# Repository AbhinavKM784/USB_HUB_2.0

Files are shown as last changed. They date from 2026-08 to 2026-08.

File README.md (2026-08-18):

# USB 4 port 2.0 Hub

A custom-designed 4-port USB 2.0 hub built around the GL850G USB Hub Controller.

## Overview

This USB hub features:

- 1 × USB C upstream port
- 2 × USB Type-A downstream ports
- 2 × USB Type-C downstream ports
- USB 2.0 High-Speed support (up to 480 Mbps)
- Plug-and-play operation

## Specifications

- Hub Controller - GL850G 
- USB Standard - USB 2.0
- Maximum Speed - 480 Mbps
- Upstream Ports - 1 
- USB-A Ports - 2 
- USB-C Ports - 2 

## Bill of Materials (BOM)

|  # | Component | Value / Part | Qty | Price (INR) | Price (USD) |
| -: | --- | --- | --: | ---: | ---: |
|  1 | PCB | Fabricated by LionCircuits | 1 | ₹1,012.00 | $10.626 |
|  2 | Capacitor | 10 µF | 2 | ₹21.60 | $0.2268 |
|  3 | Capacitor | 1 µF | 4 | ₹21.10 | $0.22155 |
|  4 | Capacitor | 22 pF | 2 | ₹20.00 | $0.210 |
|  5 | Capacitor | 100 nF | 5 | ₹19.00 | $0.1995 |
|  6 | USB IC | GL850G | 1 | ₹84.00 | $0.882 |
|  7 | USB-C Receptacle | USB 2.0, 16P | 3 | ₹71.00 | $0.7455 |
|  8 | USB-A Receptacle | Molex 67643 | 2 | ₹15.00 | $0.1575 |
|  9 | Resistor | 5.1 kΩ | 6 | ₹11.00 | $0.1155 |
| 10 | Resistor | 680 Ω | 1 | ₹13.00 | $0.1365 |
| 11 | Resistor | 10 kΩ | 1 | ₹11.00 | $0.1155 |
| 12 | Crystal | 12 MHz | 1 | ₹24.00 | $0.252 |
| 13 | Soldering Wire | 40/60, 0.8 mm | 1 | ₹53.00 | $0.5565 |
| 14 | Magnets | 3 mm Diameter × 3 mm Thick Neodymium | 8 | ₹76.00 | $0.798 |
| 15 | M2 Screws | M2 × 8 mm Phillips CSK SS 304 | 5 | ₹8.00 | $0.084 |
| 16 | M2 Brass Inserts | M2 × 6 mm Brass Threaded Inserts | 5 | ₹12.00 | $0.126 |
| | **Total** | | | **₹1,471.70** | **$15.45285** |

### Additional Hardware

* **8 × 3 mm × 3 mm neodymium magnets** — used for the enclosure's magnetic closure.
* **5 × M2 × 8 mm Phillips countersunk screws** — used for PCB mounting.
* **5 × M2 × 6 mm brass threaded inserts** — used as threaded mounting points for the PCB screws.

### Component Links

* [PCB — LionCircuits](https://www.lioncircuits.com/)
* [10 µF Capacitor — KTRON](https://www.ktron.in/product/10uf-25v-ceramic-capacitor-smd-0805/)
* [1 µF Capacitor — Robu](https://robu.in/product/gcm21br71e105ka56k-murata-electronics-25v-1uf-x7r-%c2%b110-0805-multilayer-ceramic-capacitor/)
* [22 pF Capacitor — KTRON](https://www.ktron.in/product/22pf-100v-multi-layered-ceramic-capacitor/)
* [100 nF Capacitor — KTRON](https://www.ktron.in/product/100nf-100v-ceramic-capacitor-0805/)
* [GL850G USB IC — Hubtronics](https://hubtronics.in/1884)
* [USB-C Receptacle — KTRON](https://www.ktron.in/product/mup-u20401-03-usb-type-c-16-pin-smd-connector/)
* [USB-A Receptacle — KTRON](https://www.ktron.in/product/usb-type-a-female-connector/)
* [5.1 kΩ Resistor — Robu](https://robu.in/product/erj6geyj512v-panasonic-125mw-thick-film-resistors/)
* [680 Ω Resistor — Robu](https://robu.in/product/rt0805fr-07680rl-yageo-125mw-thick-film-resistor/)
* [10 kΩ Resistor — Robu](https://robu.in/product/ac0805jr-0710kl-yageo-res-thick-film-0805-10k-ohm/)
* [12 MHz Crystal — KTRON](https://www.ktron.in/product/12-mhz-crystal-smd-hc49smd-xyc/)
* [Soldering Wire — Robu](https://robu.in/product/tin-wire-soldering-tubeus-0-8mm-40-60/)
* [3 mm × 3 mm Neodymium Magnets — OnlyScrews](https://onlyscrews.in/products/3mm-x-3mm-neodymium-disc-magnets-n35-dia-3mm-thickness-3mm)
* [M2 × 8 mm Phillips CSK Screws — OnlyScrews](https://onlyscrews.in/products/m2-x-8mm-phillips-csk-ss-304-screw-dia-2mm-length-8mm)
* [M2 × 6 mm Brass Threaded Inserts — OnlyScrews](https://onlyscrews.in/products/m2-x-6mm-brass-threaded-inserts)

### Shipping

| Supplier | Shipping (INR) | Shipping (USD) |
| --- | ---: | ---: |
| Hubtronics | ₹75.00 | $0.788 |
| Robu | ₹50.00 | $0.525 |
| Ktron | ₹77.00 | $0.809 |
| Onlyscrews | ₹59.00 | 0.7245 |

| **Shipping Total** |    **₹272.00** |     **2.8455** |

### Total Cost

| | INR | USD |
| --- | ---: | ---: |
| Components | ₹1,375.70 | $14.445 |
| Shipping | ₹202.00 | $2.121 |
| **Grand Total** | **₹1,742.70** | **$18.299** |

> **Note:** Prices are approximate and may change depending on supplier pricing and availability.

## Schematic



*Complete circuit schematic of the USB hub.*

## PCB Design



## 3D Model





## CAD Photos And Videos
Bottom Case

<video src="https://github.com/user-attachments/assets/de1a6d5d-6dac-484f-9280-b4399e31e206" controls width="800"></video>

Top Case

<video src="https://github.com/user-attachments/assets/451d31d9-74d8-4081-8db9-19cb0036360e" controls width="800"></video>


PCB 


Assembled Case

<video src="https://github.com/user-attachments/assets/695826ae-f8d0-41ed-982d-1c137125c4df" controls width="800"></video>

## Hardware Architecture

```text
          Host PC
              │
              ▼
       USB Upstream Port
              │
              ▼
          GL850G
      USB Hub Controller
        ┌────┴────┐
        │         │
   USB-A Ports  USB-C Ports
      (2x)         (2x)

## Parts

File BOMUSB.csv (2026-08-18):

PARTS
Sl no | Component | Value / Part | Qty | Link | Price (Inr) | Price(USD)
1 | PCB | Fabricated by lionscircuit | 1 | https://www.lioncircuits.com/ | 1012 | 10.626
2 | Capacitor | 10 µF | 2 | https://www.ktron.in/product/10uf-25v-ceramic-capacitor-smd-0805/ | 21.6 | 0.2268
3 | Capacitor | 1 µF | 4 | https://robu.in/product/gcm21br71e105ka56k-murata-electronics-25v-1uf-x7r-%c2%b110-0805-multilayer-ceramic-capacitors-mlcc-smd-smt-rohs/ | 21.1 | 0.22155
4 | Capacitor | 22 pF | 2 | https://www.ktron.in/product/22pf-100v-multi-layered-ceramic-capacitor/ | 20 | 0.21
5 | Capacitor | 100 nF | 5 | https://www.ktron.in/product/100nf-100v-ceramic-capacitor-0805/ | 19 | 0.1995
6 | USB IC | GL850G | 1 | https://hubtronics.in/1884 | 84 | 0.882
7 | USB-C Receptacle | USB 2.0, 16P | 3 | https://www.ktron.in/product/mup-u20401-03-usb-type-c-16-pin-smd-connector/ | 71 | 0.7455
8 | USB-A Receptacle | Molex 67643 | 2 | https://www.ktron.in/product/usb-type-a-female-connector/ | 15 | 0.1575
9 | Resistor | 5.1 kΩ | 6 | https://robu.in/product/erj6geyj512v-panasonic-125mw-thick-film-resistors-%c2%b15-%c2%b1200ppm-%e2%84%83-5-1k%cf%89-0805-chip-resistor-surface-mount-rohs/ | 11 | 0.1155
10 | Resistor | 680 Ω | 1 | https://robu.in/product/rt0805fre07680rl-yageo-125mw-thin-film-resistor-%c2%b150ppm-%e2%84%83-%c2%b11-680%cf%89-0805-chip-resistor-surface-mount-rohs/ | 13 | 0.1365
11 | Resistor | 10 kΩ | 1 | https://robu.in/product/ac0805jr-0710kl-yageo-res-thick-film-0805-10k-ohm-5-0-125w1-8w-%c2%b1100ppm-c-pad-smd-t-r-automotive-aec-q200/ | 11 | 0.1155
12 | Crystal | 12 MHz | 1 | https://www.ktron.in/product/12-mhz-crystal-smd-hc49smd-yxc/ | 24 | 0.252
13 | Soldering Wire | 40/60 0.8mm | 1 | https://robu.in/product/tin-wire-soldering-tubeus-0-8mm-40-60-8gram/ | 53 | 0.5565
14 | Magnets | 3mm Diameter Neodymium Disc Magnets N35 | 8 | https://onlyscrews.in/products/3mm-x-3mm-neodymium-disc-magnets-n35-dia-3mm-thickness-3mm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 | 76 | 0.798
15 | m2 screws | M2 X 8mm Phillips CSK | 5 | https://onlyscrews.in/products/m2-x-8mm-phillips-csk-ss-304-screw-dia-2mm-length-8mm?variant=51155018514745 | 8 | 0.084
16 | m2 brass inserts | M2 X 6mm Brass Threaded Inserts | 5 | https://onlyscrews.in/products/m2-x-6mm-brass-threaded-inserts?variant=49423242101049 | 12 | 0.126
 | Total |  |  |  | 1471.7 | 15.45285
Shipping
 | Companies | INR | USD
 | Hubtronics | 75 | 0.7875
 | Robu | 50 | 0.525
 | Ktron | 77 | 0.8085
 | OnlyScrews | 69 | 0.7245
 | Total | 271 | 2.8455
 | Combined total | 1742.7 | 18.29835

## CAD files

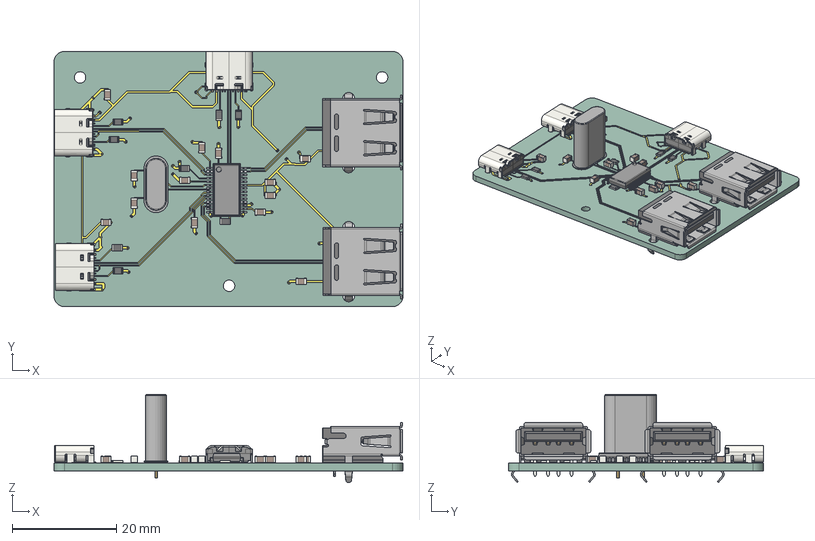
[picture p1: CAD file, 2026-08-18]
3D FILES/PCBNEW(STEP).step
67.0 x 49.0 x 16.9 mm
C_0805_2012Metric_1 x 13
R_0805_2012Metric_1 x 8
USB_A_Molex_67643_Horizontal_1 x 2
body_ssop28
pins x 14
USB_C_Receptacle_16P_TopMnt_Horizontal_GCT_USB4105-xx-A x 3
Crystal_HC49-U_Vertical_1
USBHUB_copper
USBHUB_PCB

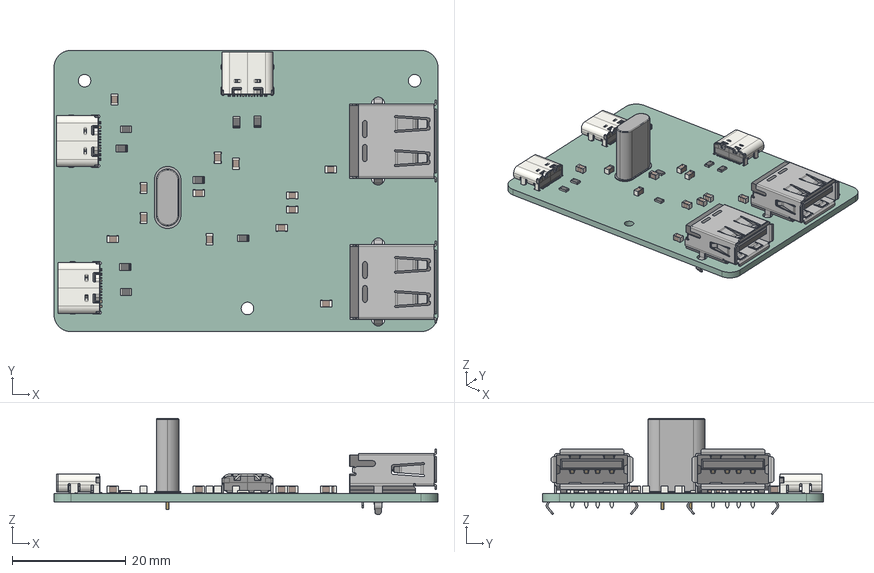
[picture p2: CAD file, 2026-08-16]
PCB/PCB.step
67.4 x 49.4 x 16.9 mm
C_0805_2012Metric x 13
R_0805_2012Metric x 8
USB_A_Molex_67643_Horizontal x 2
USB_C_Receptacle_16P_TopMnt_Horizontal_GCT_USB4105-xx-A x 3
Crystal_HC49-U_Vertical
USBHUB_PCB

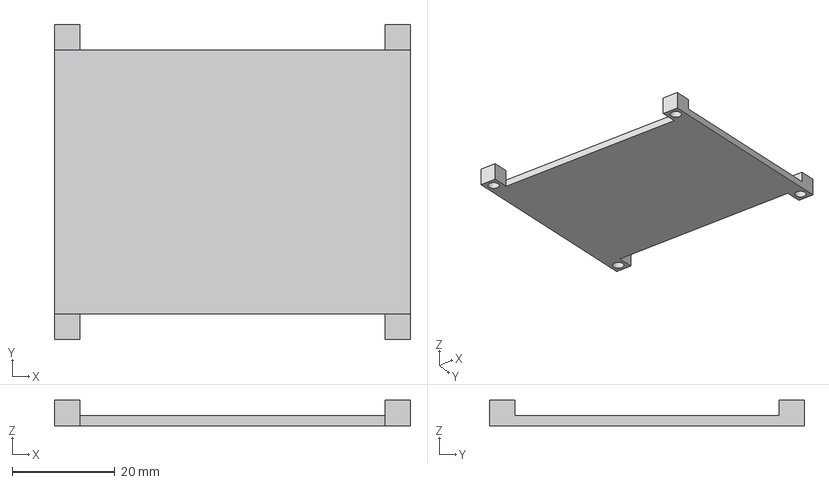
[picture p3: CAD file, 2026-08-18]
3D FILES/Case TOP NEW(STEP).step
69.3 x 61.3 x 5.00 mm

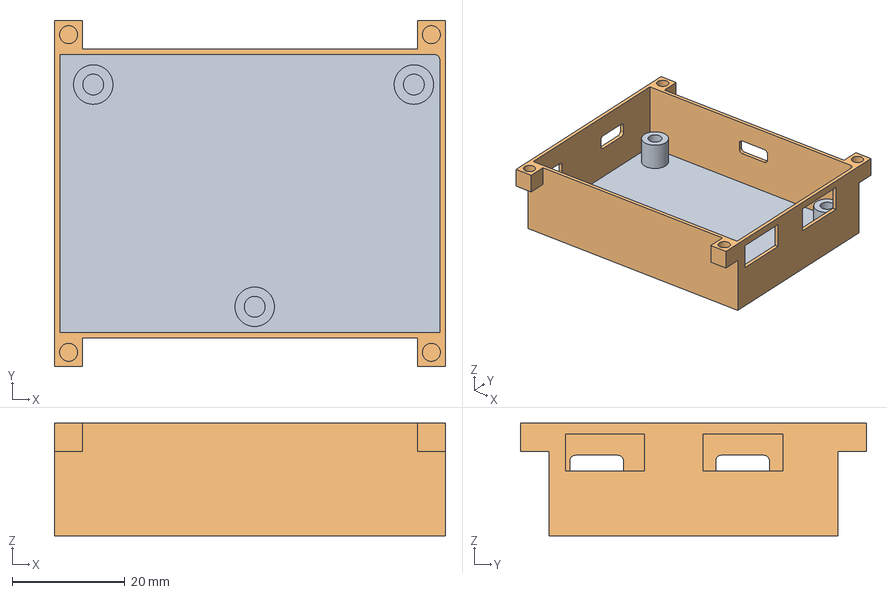
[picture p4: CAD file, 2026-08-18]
3D FILES/CASE bottom(STEP).step
69.3 x 61.3 x 20.0 mm

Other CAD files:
3D FILES/CASE bottom(f3d).f3d
3D FILES/Case TOP(f3d).f3d
3D FILES/PCBNEW(f3d).f3d

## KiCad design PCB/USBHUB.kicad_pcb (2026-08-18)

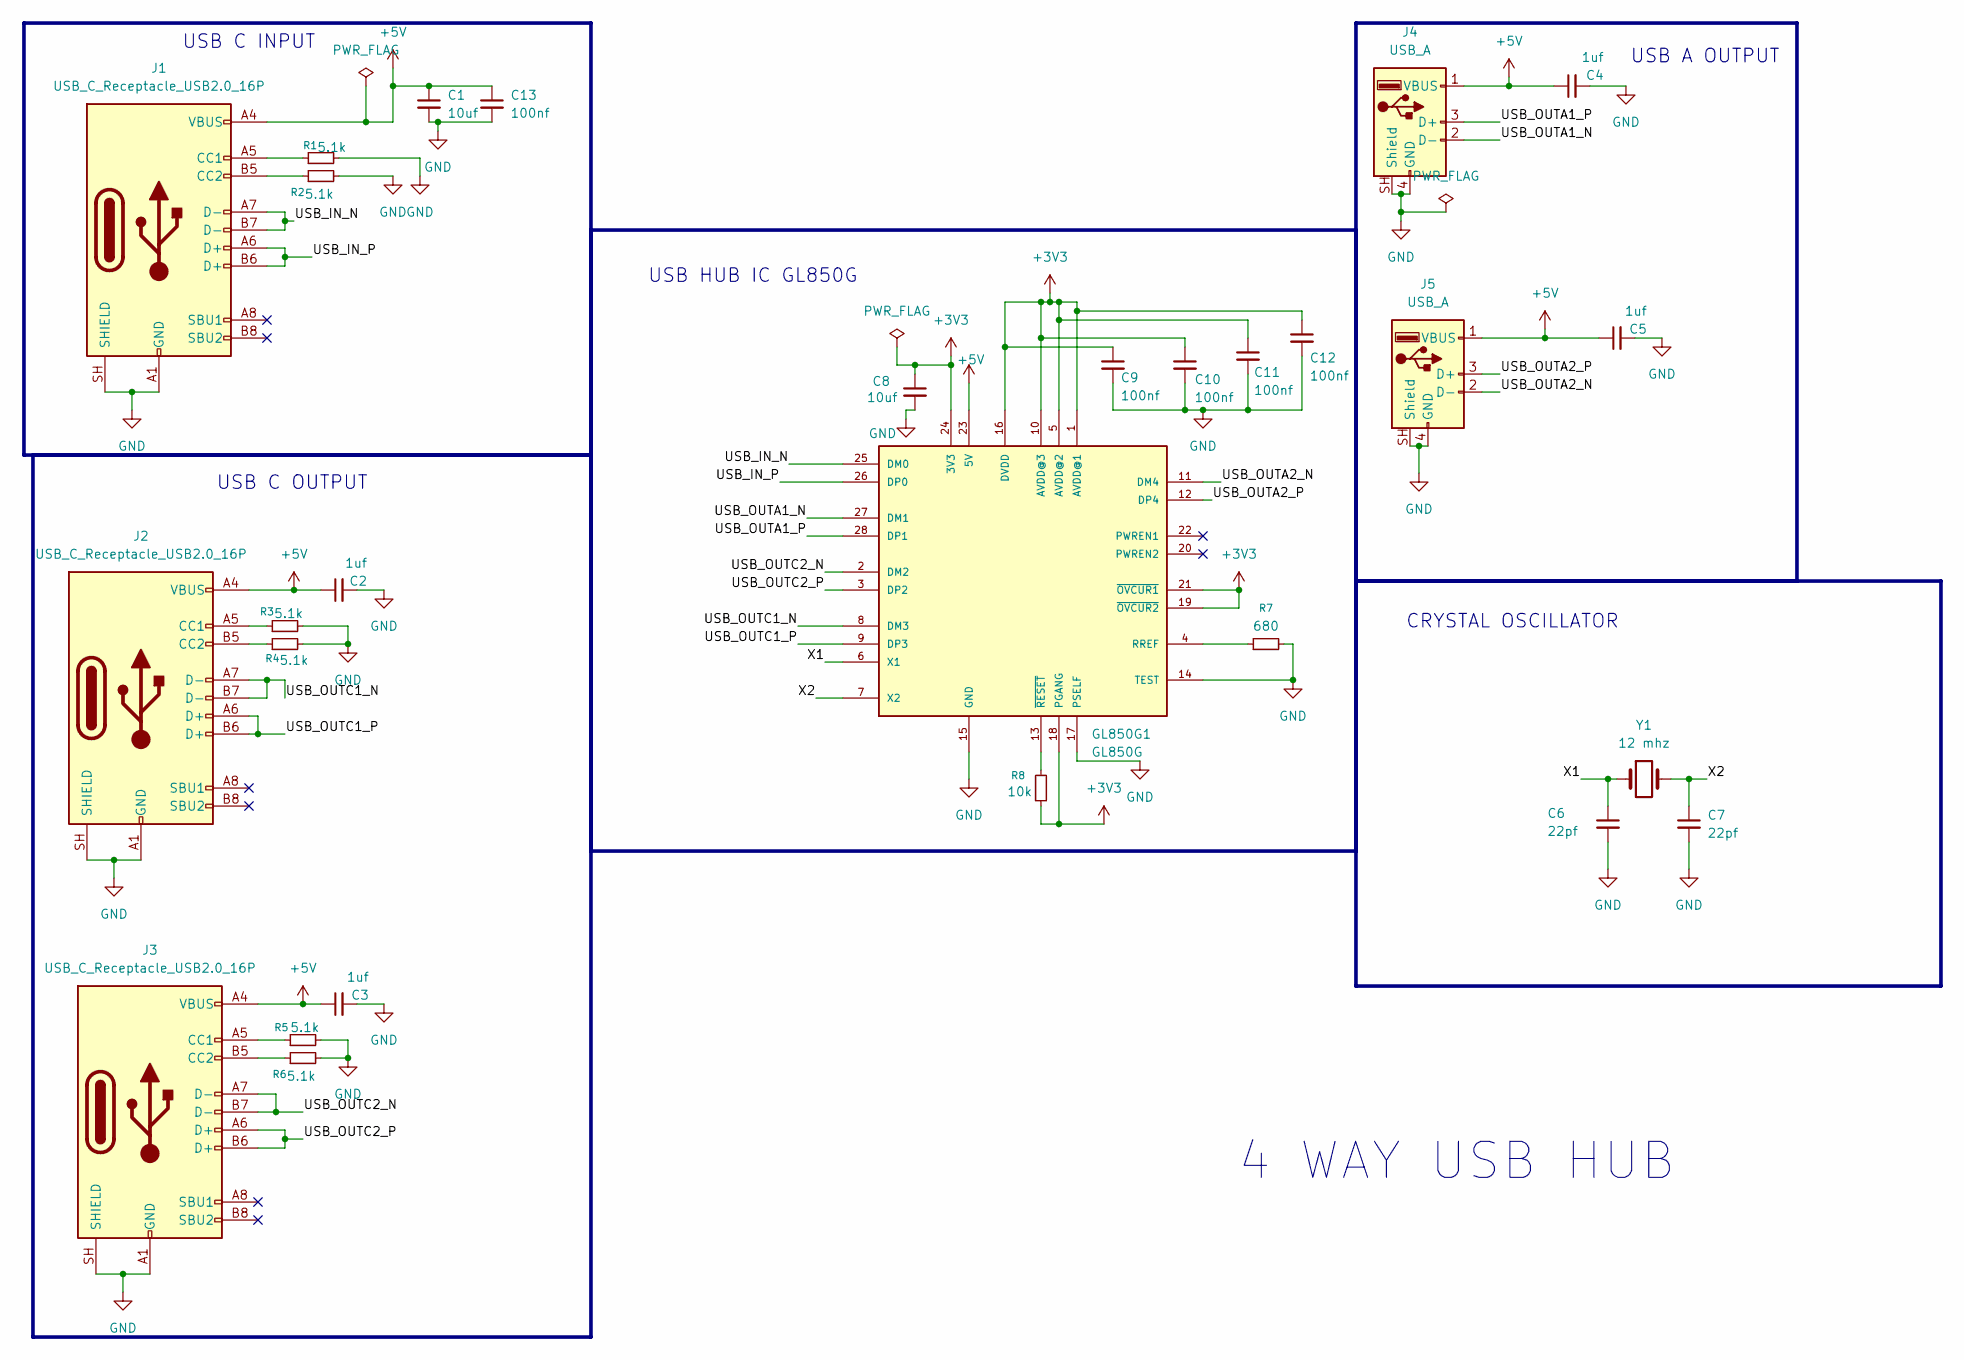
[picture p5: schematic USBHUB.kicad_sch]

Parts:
C1, C8: 10uf; C_0805_2012Metric
C2, C3, C4, C5: 1uf; C_0805_2012Metric
C6, C7: 22pf; C_0805_2012Metric
C9, C10, C11, C12, C13: 100nf; C_0805_2012Metric
GL850G1: GL850G; 28SSOP
J1, J2, J3: USB_C_Receptacle_USB2.0_16P; USB_C_Receptacle_HCTL_HC-TYPE-C-16P-01A
J4, J5: USB_A; USB_A_Molex_67643_Horizontal
R1, R2, R3, R4, R5, R6: 5.1k; R_0805_2012Metric
R7: 680; R_0805_2012Metric
R8: 10k; R_0805_2012Metric
Y1: 12 mhz; Crystal_HC49-U_Vertical

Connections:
+3V3: C8.1, C9.1, C10.1, C11.1, C12.1, GL850G1.1 (AVDD@1), GL850G1.5 (AVDD@2), GL850G1.10 (AVDD@3), GL850G1.16 (DVDD), GL850G1.18 (PGANG), GL850G1.19 (~OVCUR2), GL850G1.21 (~OVCUR1), GL850G1.24 (3V3), R8.1
+5V: C1.1, C2.1, C3.1, C4.1, C5.1, C13.1, GL850G1.23 (5V), J1.A4 (VBUS), J1.A9 (VBUS), J1.B4 (VBUS), J1.B9 (VBUS), J2.A4 (VBUS), J2.A9 (VBUS), J2.B4 (VBUS), J2.B9 (VBUS), J3.A4 (VBUS), J3.A9 (VBUS), J3.B4 (VBUS), J3.B9 (VBUS), J4.1 (VBUS), J5.1 (VBUS)
/USB_IN_N: GL850G1.25 (DM0), J1.A7 (D-), J1.B7 (D-)
/USB_IN_P: GL850G1.26 (DP0), J1.A6 (D+), J1.B6 (D+)
/USB_OUTA1_N: GL850G1.27 (DM1), J4.2 (D-)
/USB_OUTA1_P: GL850G1.28 (DP1), J4.3 (D+)
/USB_OUTA2_N: GL850G1.11 (DM4), J5.2 (D-)
/USB_OUTA2_P: GL850G1.12 (DP4), J5.3 (D+)
/USB_OUTC1_N: GL850G1.8 (DM3), J2.A7 (D-), J2.B7 (D-)
/USB_OUTC1_P: GL850G1.9 (DP3), J2.A6 (D+), J2.B6 (D+)
/USB_OUTC2_N: GL850G1.2 (DM2), J3.A7 (D-), J3.B7 (D-)
/USB_OUTC2_P: GL850G1.3 (DP2), J3.A6 (D+), J3.B6 (D+)
/X1: C6.1, GL850G1.6 (X1), Y1.1
/X2: C7.1, GL850G1.7 (X2), Y1.2
GND: C1.2, C2.2, C3.2, C4.2, C5.2, C6.2, C7.2, C8.2, C9.2, C10.2, C11.2, C12.2, C13.2, GL850G1.14 (TEST), GL850G1.15 (GND), GL850G1.17 (PSELF), J1.A1 (GND), J1.A12 (GND), J1.B1 (GND), J1.B12 (GND), J1.SH (SHIELD), J2.A1 (GND), J2.A12 (GND), J2.B1 (GND), J2.B12 (GND), J2.SH (SHIELD), J3.A1 (GND), J3.A12 (GND), J3.B1 (GND), J3.B12 (GND), J3.SH (SHIELD), J4.4 (GND), J4.SH (Shield), J5.4 (GND), J5.SH (Shield), R1.2, R2.2, R3.2, R4.2, R5.2, R6.2, R7.2
unnamed: GL850G1.4 (RREF), R7.1
unnamed: GL850G1.13 (~RESET), R8.2
unnamed: J1.A5 (CC1), R1.1
unnamed: J1.B5 (CC2), R2.1
unnamed: J2.A5 (CC1), R3.1
unnamed: J2.B5 (CC2), R4.1
unnamed: J3.A5 (CC1), R5.1
unnamed: J3.B5 (CC2), R6.1

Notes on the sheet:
USB HUB IC GL850G
CRYSTAL OSCILLATOR
4 WAY USB HUB
USB C OUTPUT
USB A OUTPUT
USB C INPUT

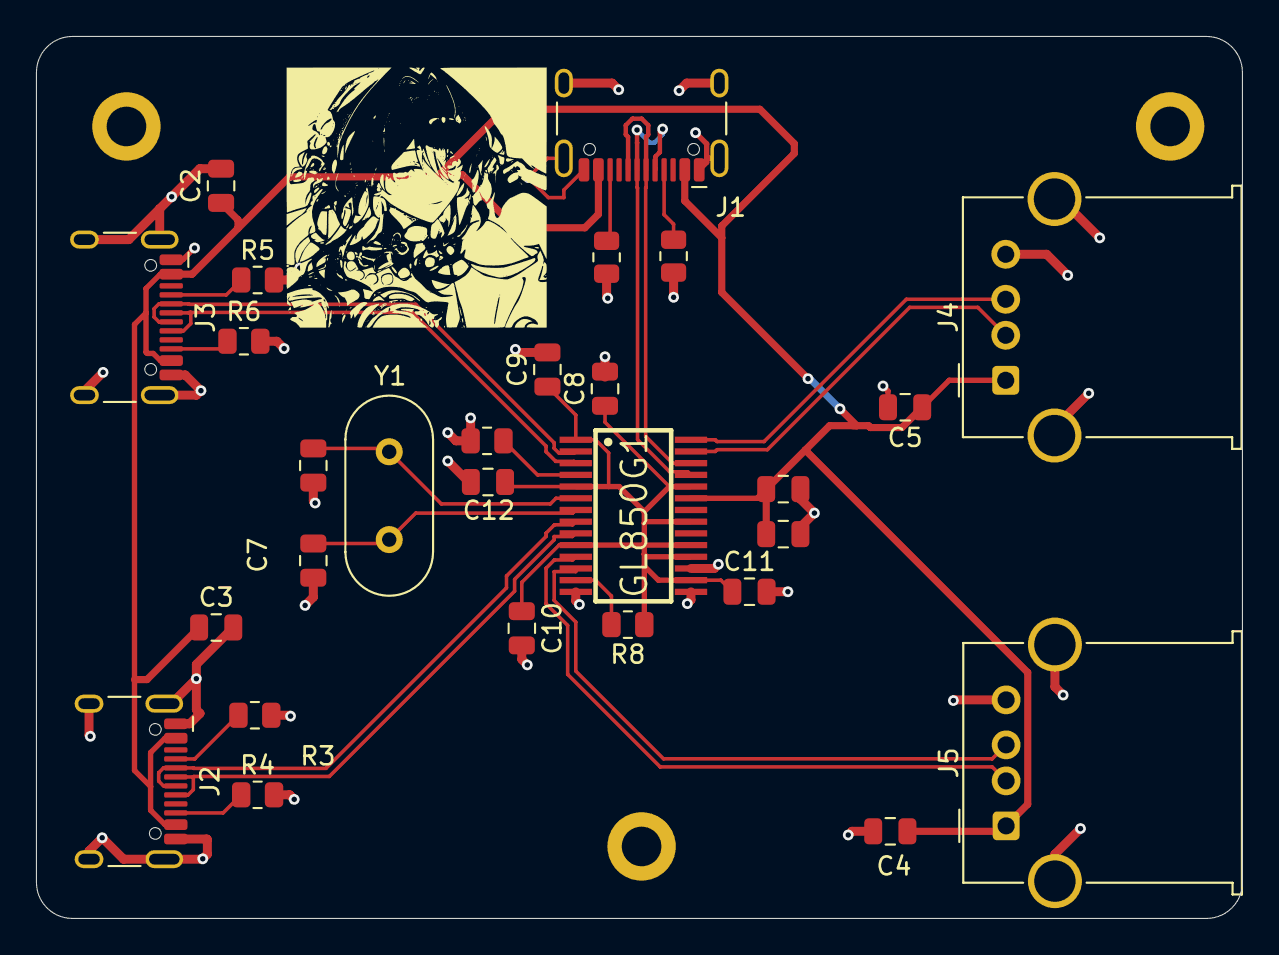
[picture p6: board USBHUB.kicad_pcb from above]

Board: 2 copper layers, 67.0 x 49.0 mm, 28 parts (0 on the bottom side), 23 nets.

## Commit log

2026-06-11 Create PCB Folder
2026-06-11 FULL README UPDATE
    Expanded the README to include detailed specifications, schematic, PCB design, and 3D model visualizations for the USB 2.0 hub.
2026-08-16 Modified BOM File and created a 3d file of pcb
    [BOM.csv, BOMUSB.xlsx, PCB.step]
2026-08-18 3d Files
    [BOMUSB.csv, BOMUSB.xlsx, CASE bottom(STEP).step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]
2026-08-18 PCB UPDATE
    [USBHUB.kicad_pcb]
2026-08-18 Revise README for USB hub specifications and content
    Updated the README to reflect the change from a USB 2.0 hub to a USB 4-port 2.0 hub, revised the Bill of Materials table, and added CAD photos and videos.
2026-08-18 commit bom
    sd
    [BOMUSB.csv]
